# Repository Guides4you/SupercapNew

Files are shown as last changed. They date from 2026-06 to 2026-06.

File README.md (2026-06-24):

# Supercap New

A concise guide to the **Supercap New** project: repository layout, build requirements, programming instructions, hardware notes, and TAG configuration.

---

## Folder structure
- **Firmware** — firmware source code.  
- **Images** — binary firmware files.  
- **Hardware** — Altium project files and production outputs.

---

## Firmware
- **Required tools**: Visual Studio Code and **nRF Connect SDK v2.3.0**.  
- **Important**: builds will fail with other SDK versions; use exactly **v2.3.0** for reliable results.  
---

## Images and Programming
- **Target MCU**: **nRF52805**.  
- **Programmers supported**: Segger (J-Flash), Nordic programmer (`nrfjprog`), or other Segger tools.  
- **Common issue**: if the board’s **RESET** pin is not configured as a GPIO, the board may not boot after programming.  
- **Post-programming step (Windows)**: if needed, run the UICR erase command to restore RESET behavior:

`nrfjprog --eraseuicr -f NRF52`

---

## Hardware
- **Open with**: Altium Designer.  
- **Project outputs**: two production variants are included (with and without ePaper). Each variant contains production files and PDF schematics.  

---

## TAG configuration
- **Purpose**: TAGs are programmed with a **URI string** (web address) and an optional text configuration file.  
- **Configuration format**: `+pwr+adv+ep`  
- **pwr** — Bluetooth transmit power (integer).
  
| pwr value | nRF52 TX Power Setting |
|---|---|
| 0 | -40 dBm |
| 1 | -20 dBm |
| 2 | -16 dBm |
| 3 | -12 dBm |
| 4 | -8  dBm |
| 5 | -4  dBm |
| 6 | 0 dBm |
| 7 | +3  dBm |
| 8 | +4  dBm | 
- **adv** — advertising time in **seconds × 10** (integer).  
- **ep** — ePaper flag: `1` = enabled, `0` = disabled.  
- **Default configuration**:
> +6+10+1

- **Behavior**: after the first boot the configuration file is hidden; every time the TAG is written the device reboots.

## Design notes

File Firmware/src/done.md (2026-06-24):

# Modifiche eseguite

## Pinout e devicetree

1. `DISP_CS` spostato su `P0.21`
   - Label devicetree: `csgpios`
   - File: `../g4y_beacon_supercap.overlay`
   - Nota: `P0.21` nasce come reset, ma il progetto ha `CONFIG_GPIO_AS_PINRESET=n` in `prj.conf` e `prj_debug.conf`.

2. `GPO` della memoria NFC collegato a `P0.04`
   - Label devicetree: `nfcgpo`
   - File: `../g4y_beacon_supercap.overlay`
   - `VOUTNFC` non e' piu' usato come ingresso GPIO.

## Migrazione NFC a ST25DV04KC

3. Aggiornati indirizzi e registri base del driver NFC
   - User memory I2C: `0x53`
   - System memory I2C: `0x57`
   - Dynamic registers: `0x2000+`
   - File: `NfcTag.h`, `NfcTag.c`

4. Adattata la dimensione memoria per ST25DV04KC
   - `EEPROM_I2C_LENGTH` portato a `512` byte.

5. Disattivate le vecchie logiche M24LR non compatibili
   - Vecchie funzioni password/protection M24LR rese no-op dove non direttamente compatibili.
   - Mantenuta l'API esistente per non rompere il resto del firmware.

6. Aggiunta protezione base sul parsing NDEF URL
   - Il buffer URL viene terminato con `\0`.
   - Limitata la copia rispetto a `URL_BUFFER`.

## GPO e rilevamento scrittura NFC

7. Configurato `GPO` per segnalare scritture RF/NFC in EEPROM
   - `GPO1 = GPO_EN | RF_WRITE_EN`
   - La configurazione usa la password I2C factory-default a zero.
   - La password NFC/RF resta indipendente e puo' essere cambiata in produzione.

8. Gestione interrupt su GPO
   - `P0.04` configurato come input.
   - Interrupt su `GPIO_INT_EDGE_FALLING`, coerente con ST25DV04KC TSSOP open-drain e pull-up esterno.
   - Al trigger viene letto `IT_STS_Dyn` e si procede solo se il bit `RF_WRITE` e' attivo.

9. Logica post-scrittura NFC invariata lato comportamento applicativo
   - Dopo scrittura NFC, il firmware rileggge i dati.
   - Se URL/power/adv/epaper cambiano, esegue `sys_reboot(SYS_REBOOT_COLD)`.
   - L'aggiornamento BLE advertising avviene al boot successivo ricostruendo payload e parametri dai dati NFC.

## Energy harvesting / supercap

10. Configurata Energy Harvesting in modalita' on-demand
    - `EH_MODE = 1`
    - `EH_CTRL_Dyn.EH_EN` disabilitato durante init e prima della rilettura NFC.
    - `EH_CTRL_Dyn.EH_EN` abilitato dopo boot/lettura/display update e dopo gestione evento NFC.

11. Sequenza compatibile con AN4913
    - Energy harvesting disabilitato durante la fase critica di comunicazione NFC/RF.
    - Energy harvesting riabilitato solo dopo completamento lettura/scrittura, per ricaricare il supercap tramite `V_EH`.

## E-paper opzionale

12. Aggiunta define compile-time per presenza e-paper
    - File: `../inc/main.h`
    - Define: `DEVICE_HAS_EPAPER`

13. Disattivate le logiche display quando `DEVICE_HAS_EPAPER == 0`
    - Escluse chiamate a:
      - `Epaper_InitQR()`
      - `Epaper_Init()`
      - `Epaper_PrintQR()`
      - `Epaper_Gosleep()`
    - L'aggiornamento dei dati BLE da NFC resta attivo anche senza e-paper.

## Note di verifica

14. P0.21 come GPIO
    - Il firmware/devicetree lo configura come GPIO.
    - Su hardware gia' programmato va verificato `UICR.PSELRESET`: se contiene ancora `P0.21`, serve cancellazione UICR/recover.

15. Build non eseguita
    - `west`, `cmake` e `ninja` non risultano disponibili nel PATH della shell usata.

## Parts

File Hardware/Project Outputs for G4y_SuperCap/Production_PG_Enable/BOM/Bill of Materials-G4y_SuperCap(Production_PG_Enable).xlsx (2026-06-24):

Name | Description | Designator | Footprint | Quantity | Value | PartNumber | LCSC | LCSC_Alt_1 | LCSC_Alt_2
Cap_0402_100n/16V | 16V 100nF X7R ±10% 0402 Multilayer Ceramic Capacitors MLCC - SMD/SMT ROHS | C3, C17, C21, C24, C27 | C0402 | 5 | 100nF/16V | CL05B104KO5NNNC | C1525 | C22435936 | C576716
Cap_0402_10nF/50V | 10nF ±10% 50V Ceramic Capacitor X7R 0402 | C25 | C0402 | 1 | 10nF/50V | CL05B103KB5NNNC | C15195 | C6119808 | C5137480
Cap_0603_1uF/50V | 50V 1uF X5R ±10% 0603 Ceramic Capacitors ROHS | C16, C22 | C0603 | 2 | 1uF/50V | CL10A105KB8NNNC | C15849 | C6119852 | C380313
R_R0402_0R | 0Ω 62.5mW 50V Thick Film Resistor ±5% 0402 Chip Resistor - Surface Mount ROHS | R14, R33 | R0402 | 2 | 0r | 0402WGJ0000TCE | C21376 | C106231 | C2906877
R_R0402_1M5 | 1.5MΩ ±1% 62.5mW 0402 Thick Film Resistor | R11 | R0402 | 1 | 1M5 | 0402WGF1504TCE | C22276 | C49653927 | C2930014
R_R0402_22R | 22Ω ±1% 62.5mW 0402 Thick Film Resistor | R19, R20, R21, R22, R23, R24, R25, R27, R30 | R0402 | 9 | 22R | 0402WGF220JTCE | C25092 | C49654869 | C2929994
R_R0402_39r | 39Ω ±1% 62.5mW 0402 Thick Film Resistor | R32 | R0402 | 1 | 39r | 0402WGF390JTCE | C25110 | C2770700 | C2909354
R_R0402_1k | 0402, 1% ,63mW | R34 | R0402 | 1 | 1k | 0402WGJ0102TCE | C25543
R_R0402_100k | 0402, 1% ,63mW | R31 | R0402 | 1 | 100k | ERA-2VEB1003X | C25741
R_R0402_4k7 | 0402, 1% ,63mW | R28, R29 | R0402 | 2 | 4k7 | 0402WGF4701TCE | C25900
R_R0402_1M | 1MΩ ±1% 62.5mW 0402 Thick Film Resistor | R16, R18 | R0402 | 2 | 1M | 0402WGF1004TCE | C26083 | C2909328 | C2770623
R_R0402_221k | 221kΩ ±1% 62.5mW 0402 Thick Film Resistor | R3, R4, R9, R10 | R0402 | 4 | 221k | 0402WGF2213TCE | C26998 | C2998126 | C49653699
Cap_0402_1uF/25V | 1uF ±10% 25V Ceramic Capacitor X5R 0402 | C4, C5, C6, C7, C8, C9, C11, C14 | C0402 | 8 | 1uF/25V | CL05A105KA5NQNC | C52923 | C7393852 | C7472946
MBR0530T1G | Diode 30V 500mA Surface Mount SOD-123 | D1, D2, D3 | FP-SOD123-MFG | 3 |  | MBR0530T1G | C82046 | C5204746 | C236079
Diode_1N4148WT | Diode Independent 80V 125mA Surface Mount SOD-523 | D5 | SODFL160X65-2N | 1 |  | 1N4148WT-7 | C83482 | C727112 | C5381437
Cap_1206_47uF/10V | 47uF ±20% 10V Ceramic Capacitor X5R 1206 | C10 | C1206 | 1 | 47uF/10V | CL31A476MPHNNNE | C96123 | C7432787 | C6119971
Cap_0805_22uF/16V | 22uF ±20% 16V Ceramic Capacitor X5R 0805 | C1, C2, C12, C23 | C0805 | 4 | 22uF/16V | CL21A226MOQNNNE | C98190 | C33546008 | C6119898
BSS84AKBSS84AK,215 | P-Channel 50V 180mA 420mW Surface Mount SOT-23 | Q2 | SOT-23-3 | 1 |  | BSS84AK,215 | C127273 | C549760 | C7379993
TPS22860DBVR | Ultra-Low Leakage Current Single-Channel Load Switch | U2 | SOT-23-6 | 1 |  | TPS22860DBVR | C132005
PMV65UNER | N-Channel 20V 2.8A 940mW Surface Mount SOT-23 | Q1 | SOT-23-3 | 1 |  | PMV65UNER | C179446
10uH_1.44A_NRS4018T100MDGJ | 1.2A 10uH ±20% 1.3A 150mΩ SMD,4x4mm Fixed Inductors RoHS | L2 | FP-NRS4018-MFG | 1 | 10uH |  | C222882 | C2041931
R_R0402_2M7 | 2.7MΩ ±1% 62.5mW 0402 Thick Film Resistor | R13 | R0402 | 1 | 2M7 | 0402WGF2704TCE | C270621 | C3013160 | C49653355
Cap_0603_4u7F/35V | 4.7uF ±10% 35V Ceramic Capacitor X5R 0603 | C15 | C0603 | 1 | 4u7F/25V | CL10A475KL8NRNC | C307467 | C6119851 | C22367829
R_R0402_0r47 | 0402, 1% ,63mW | R17 | R0402 | 1 | 0r47 | RL0402JR-070R47L | C423162
R_R0402_2M55 | 2.55MΩ ±1% 62.5mW 0402 Thick Film Resistor | R15 | R0402 | 1 | 2M55 | 0402WGF2554TCE | C423206 | C477654 | 2612093
R_R0402_18M | 0402, 1% ,63mW | R2 | R0402 | 1 | 18M | 0402WGF1805TCE | C423222
R_R0402_4M7 | 4.7MΩ ±1% 62.5mW 0402 Thick Film Resistor | R1, R12 | R0402 | 2 | 4M7 | 0402WGF4704TCE | C474132 | C354978 | C49654986
ADP5091ACPZ-2-R7 | -40℃~+125℃ 100mV~3.3V 1A 2V 360nA Charging IC、Protection IC Not supported Supercapacitor、Lithium Battery LFCSP-24(4x4) Battery Management ROHS | U1 | FP-CP-24-14-IPC_B | 1 |  | ADP5091ACPZ-2-R7 | C579259
R_R0402_6M65 | 6.65MΩ ±1% 62.5mW 0402 Thick Film Resistor | R5, R6, R8 | R0402 | 3 | 6M65 | 0402WGF6654TCE | C620472 | C172116 | C477773
F3311A7H121024E200 | FFC/FPC Connector 24 Position 0.5mm Pitch Double-Sided Contacts, Top and Bottom Entry Surface Mount, Right Angle -55℃~+85℃ | CN1 | F3311A7H121024E200 | 1 |  | F3311A7H121024E200 | C3168055 | C52722656 | C48678015
Inductor_22uH_550mA | 550mA 22uH ±20% 685mΩ 650mA 1210 Fixed Inductors RoHS | L1 | FP-LQH32PB_NC-MFG | 1 | 22uH |  | C4153652 | C53224120 | C22463994
ST25DV04KC-IE6T3 | 53Kbit/s ISO 15693,NFC I2C TSSOP-8 RFID, RF Access, Monitoring ICs RoHS | U4 | TSOP65P640X120-8N | 1 |  | ST25DV04KC-IE6T3 | C5221719 | C5267455
BLE Module | Bluetooth Modules - 802.15.1 Bluetooth Low Energy, BLE 5.2 Module using Nordic nRF52805 SoC with integrated antenna | U3 | BC805M | 1 |  | BC805M | C6751361
Cap_0805_4u7F/50V | 4.7uF ±10% 50V Ceramic Capacitor X5R 0805 | C13 | C0805 | 1 | 4u7F/50V | HGC0805R5475K500NSLJ | C7472969 | C513770 | C2903668

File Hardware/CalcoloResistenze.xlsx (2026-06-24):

 | Vref | 1.011
 |  |  |  |  |  |  |  |  | r avab
R7 | RBK1 | 0 |  | VSETBK |  |  |  |  | 0.15 | VSETPG_RISING | 3.80
R14 | RBK2 | 0 |  |  | VSETBK | #DIV/0! | Passaggio dalla batteria di backup |  | 0.221 | VSETPG_FALLING | 2.50
 |  |  |  |  |  |  |  |  | 2.32
R8 | RTERM1 | 6.65 |  | VBAT_TERM | VBAT_TERM | 5.47 | Termine carica |  | 2.55 | RPG1 | 6.7
R15 | RTERM2 | 2.55 |  |  | VBAT_TERM_HYS | 5.31 |  |  | 2.7 | RPG_HYST | 1.5
 |  |  |  |  |  |  |  |  | 3.32 | RPG2 | 2.9
R6 | RPG1 | 6.65 |  | VSETPG_RISING VSETPG_FALLING |  |  |  |  | 3.48
R11 | RPG_HYST | 1.5 |  |  | VSETPG_RISING | 3.76 | PG alzato | 1.25 | 3.74
R13 | RPG2 | 3 |  |  | VSETPG_FALLING | 2.51 | PG abbassato |  | 4.7
 |  |  |  |  |  |  |  |  | 9.1
R5 | Rsd1 | 6.65 |  | VSETSD | VSETSD_HYS |  |  |  | 10
R12 | Rsd2 | 4.7 |  |  | VSETSD | 2.44 | Protezione csarica batteria |  | 18
 |  |  |  |  | VSYS_CHG | 2,19 | Start Charging BAT Threshold on SYS
 |  |  |  |  | VSYS_CHG_HYS | 2.04
 |  |  |  |  | VSYS_TH | 1,87 | V cold start
 |  |  |  |  | 0V
Demoboard value
 | Vref | 1.011 |  |  | VSETBK | 2.53 | Passaggio dalla batteria di backup
R5 | Rsd1 | 5.9 | 6.65
RR12 | Rsd2 | 4.12 | 3.48
R6 | RPG1 | 6.19 | 6.65 |  | VBAT_TERM | 3.69 | Termine carica
R11 | RPG_HYST | 0.1 | 1 |  | VBAT_TERM_HYS | 3.58
R13 | RPG2 | 3.83 | 2.32
 |  |  |  |  | VSETPG_RISING | 2.67 | PG alzato
R7 | RBK1 | 6.04 | 6.65 |  | VSETPG_FALLING | 2.60 | PG abbassato
R14 | RBK2 | 4.02 | 3.32
 |  |  |  |  | VSETSD_HYS
R8 | RTERM1 | 5.9 | 6.65 |  | VSETSD | 2.46 | Protezione csarica batteria
R15 | RTERM2 | 4.12 | 3.74
 |  |  |  |  | VSYS_CHG | 2,19 | Start Charging BAT Threshold on SYS
 |  |  |  |  | VSYS_CHG_HYS | 2.04
 |  |  |  |  | VSYS_TH | 1,87 | V cold start
 |  |  |  |  | 0V

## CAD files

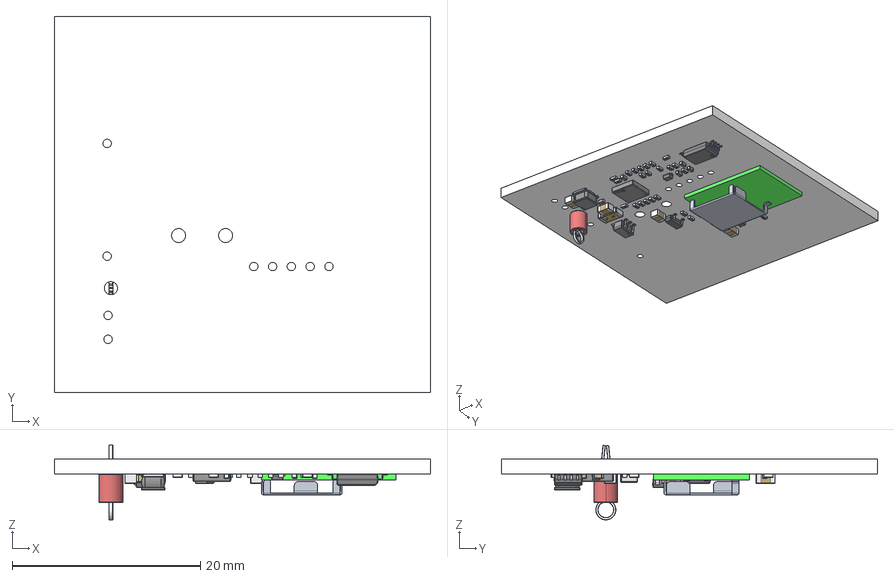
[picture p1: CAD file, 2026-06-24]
Hardware/Project Outputs for G4y_SuperCap/Production_PG_Enable_noDisplay/ExportSTEP/G4y_SuperCap(Production_PG_Enable_noDisplay).step
40.0 x 40.0 x 7.96 mm
LEAD x 6
Texas Logo Yury - Copy
Texas Logo Yury
User Library-R_0402 x 23
lead x 2
User Library-Capacitor 0402 x 6
TEST POINT RED D1mm
User Library-CAPC2013X10 x 4
pads
Analog Devices Logo
Murata
BC805
BC805M
Leader x 8
SOT23

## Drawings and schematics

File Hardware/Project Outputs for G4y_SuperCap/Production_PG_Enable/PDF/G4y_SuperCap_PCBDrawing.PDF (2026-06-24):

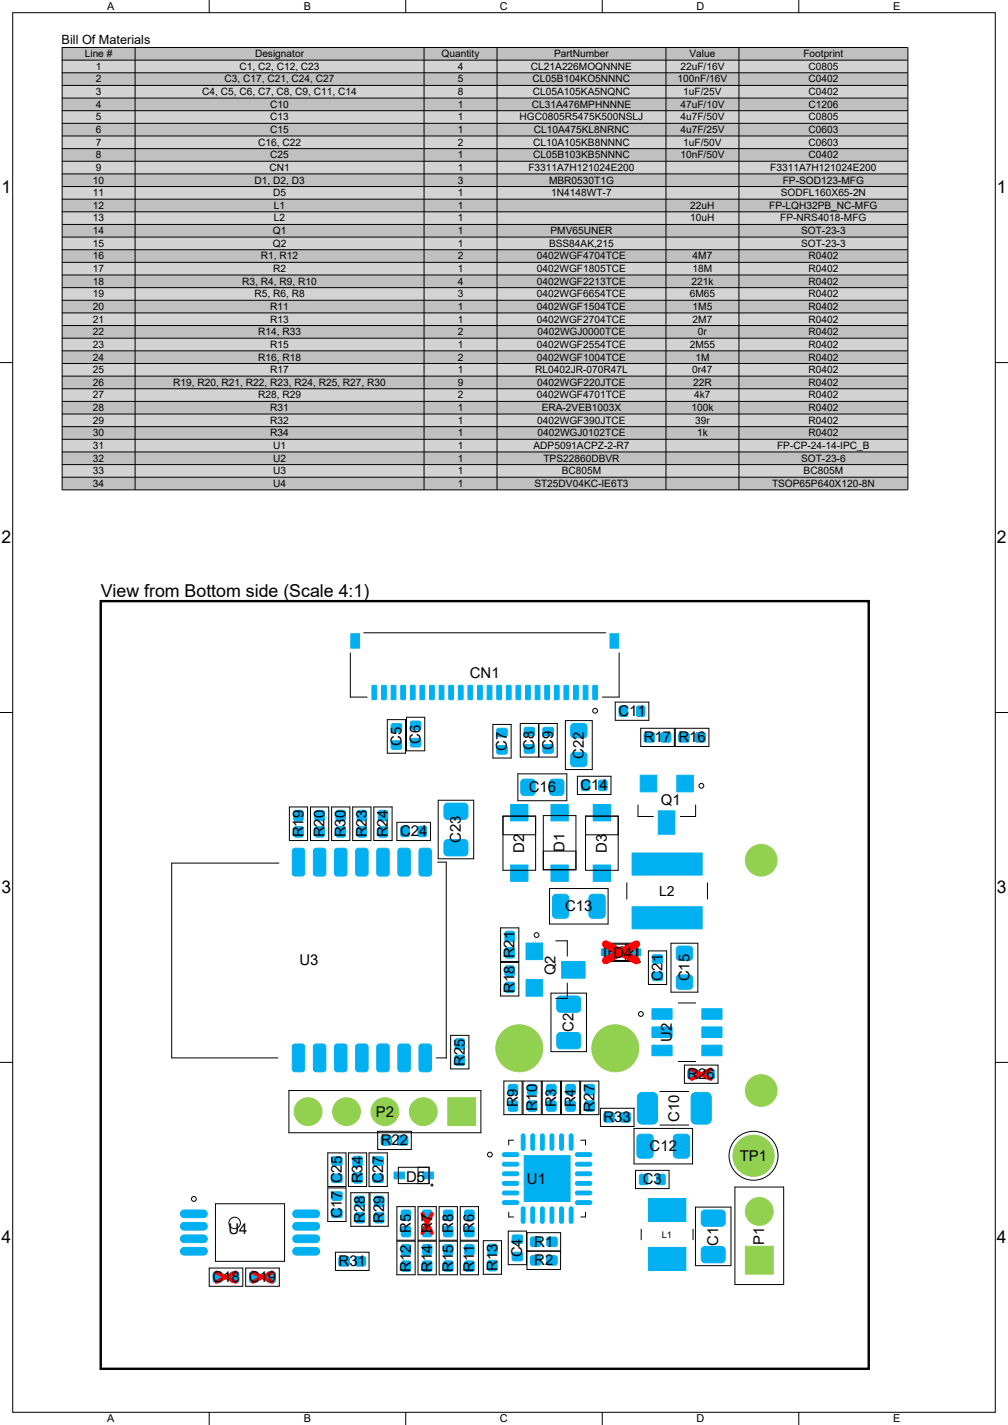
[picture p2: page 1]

Line # | Designator | Quantity | PartNumber | Value | Footprint
1 | C1, C2, C12, C23 | 4 | CL21A226MOQNNNE | 22uF/16V | C0805
2 | C3, C17, C21, C24, C27 | 5 | CL05B104KO5NNNC | 100nF/16V | C0402
3 | C4, C5, C6, C7, C8, C9, C11, C14 | 8 | CL05A105KA5NQNC | 1uF/25V | C0402
4 | C10 | 1 | CL31A476MPHNNNE | 47uF/10V | C1206
5 | C13 | 1 | HGC0805R5475K500NSLJ | 4u7F/50V | C0805
6 | C15 | 1 | CL10A475KL8NRNC | 4u7F/25V | C0603
7 | C16, C22 | 2 | CL10A105KB8NNNC | 1uF/50V | C0603
8 | C25 | 1 | CL05B103KB5NNNC | 10nF/50V | C0402
9 | CN1 | 1 | F3311A7H121024E200 | | F3311A7H121024E200
10 | D1, D2, D3 | 3 | MBR0530T1G | | FP-SOD123-MFG
11 | D5 | 1 | 1N4148WT-7 | | SODFL160X65-2N
12 | L1 | 1 | | 22uH | FP-LQH32PB_NC-MFG
13 | L2 | 1 | | 10uH | FP-NRS4018-MFG
14 | Q1 | 1 | PMV65UNER | | SOT-23-3
15 | Q2 | 1 | BSS84AK,215 | | SOT-23-3
16 | R1, R12 | 2 | 0402WGF4704TCE | 4M7 | R0402
17 | R2 | 1 | 0402WGF1805TCE | 18M | R0402
18 | R3, R4, R9, R10 | 4 | 0402WGF2213TCE | 221k | R0402
19 | R5, R6, R8 | 3 | 0402WGF6654TCE | 6M65 | R0402
20 | R11 | 1 | 0402WGF1504TCE | 1M5 | R0402
21 | R13 | 1 | 0402WGF2704TCE | 2M7 | R0402
22 | R14, R33 | 2 | 0402WGJ0000TCE | 0r | R0402
23 | R15 | 1 | 0402WGF2554TCE | 2M55 | R0402
24 | R16, R18 | 2 | 0402WGF1004TCE | 1M | R0402
25 | R17 | 1 | RL0402JR-070R47L | 0r47 | R0402
26 | R19, R20, R21, R22, R23, R24, R25, R27, R30 | 9 | 0402WGF220JTCE | 22R | R0402
27 | R28, R29 | 2 | 0402WGF4701TCE | 4k7 | R0402
28 | R31 | 1 | ERA-2VEB1003X | 100k | R0402
29 | R32 | 1 | 0402WGF390JTCE | 39r | R0402
30 | R34 | 1 | 0402WGJ0102TCE | 1k | R0402
31 | U1 | 1 | ADP5091ACPZ-2-R7 | | FP-CP-24-14-IPC_B
32 | U2 | 1 | TPS22860DBVR | | SOT-23-6
33 | U3 | 1 | BC805M | | BC805M
34 | U4 | 1 | ST25DV04KC-IE6T3 | | TSOP65P640X120-8N

View from Bottom side (Scale 4:1)

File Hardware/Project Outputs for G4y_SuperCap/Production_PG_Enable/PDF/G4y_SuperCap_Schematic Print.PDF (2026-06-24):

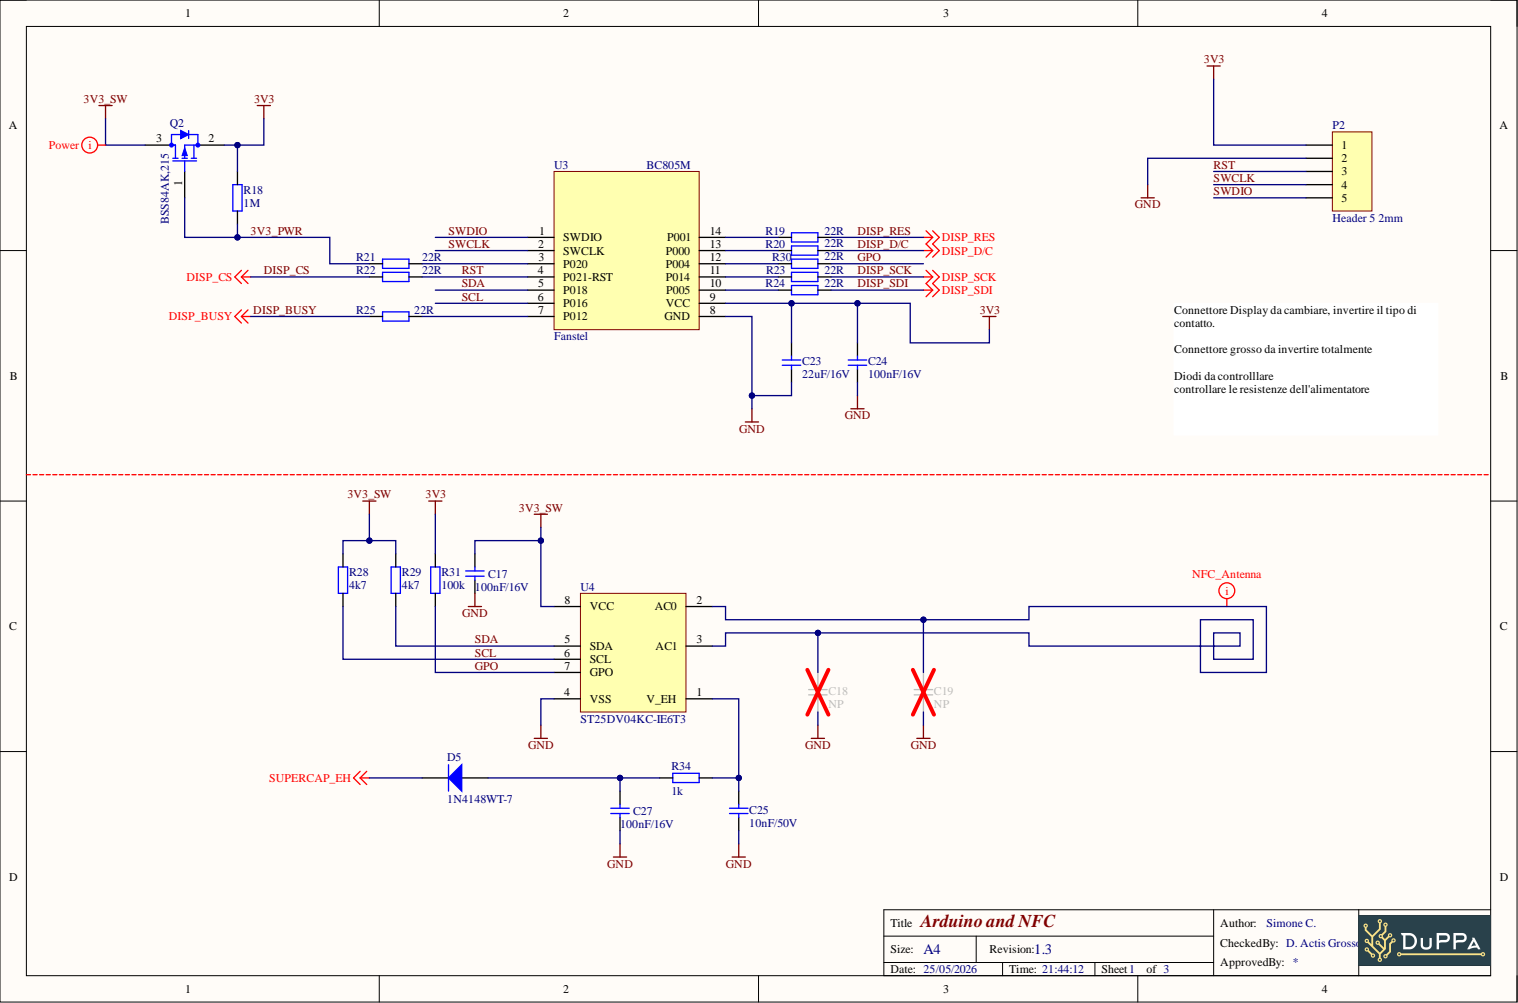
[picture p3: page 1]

Connettore Display da cambiare, invertire il tipo di
contatto.

Connettore grosso da invertire totalmente

Diodi da controlllare
controllare le resistenze dell'alimentatore

GND SDA | SDA 5

SCL | SCL 6
GPO | GPO 7

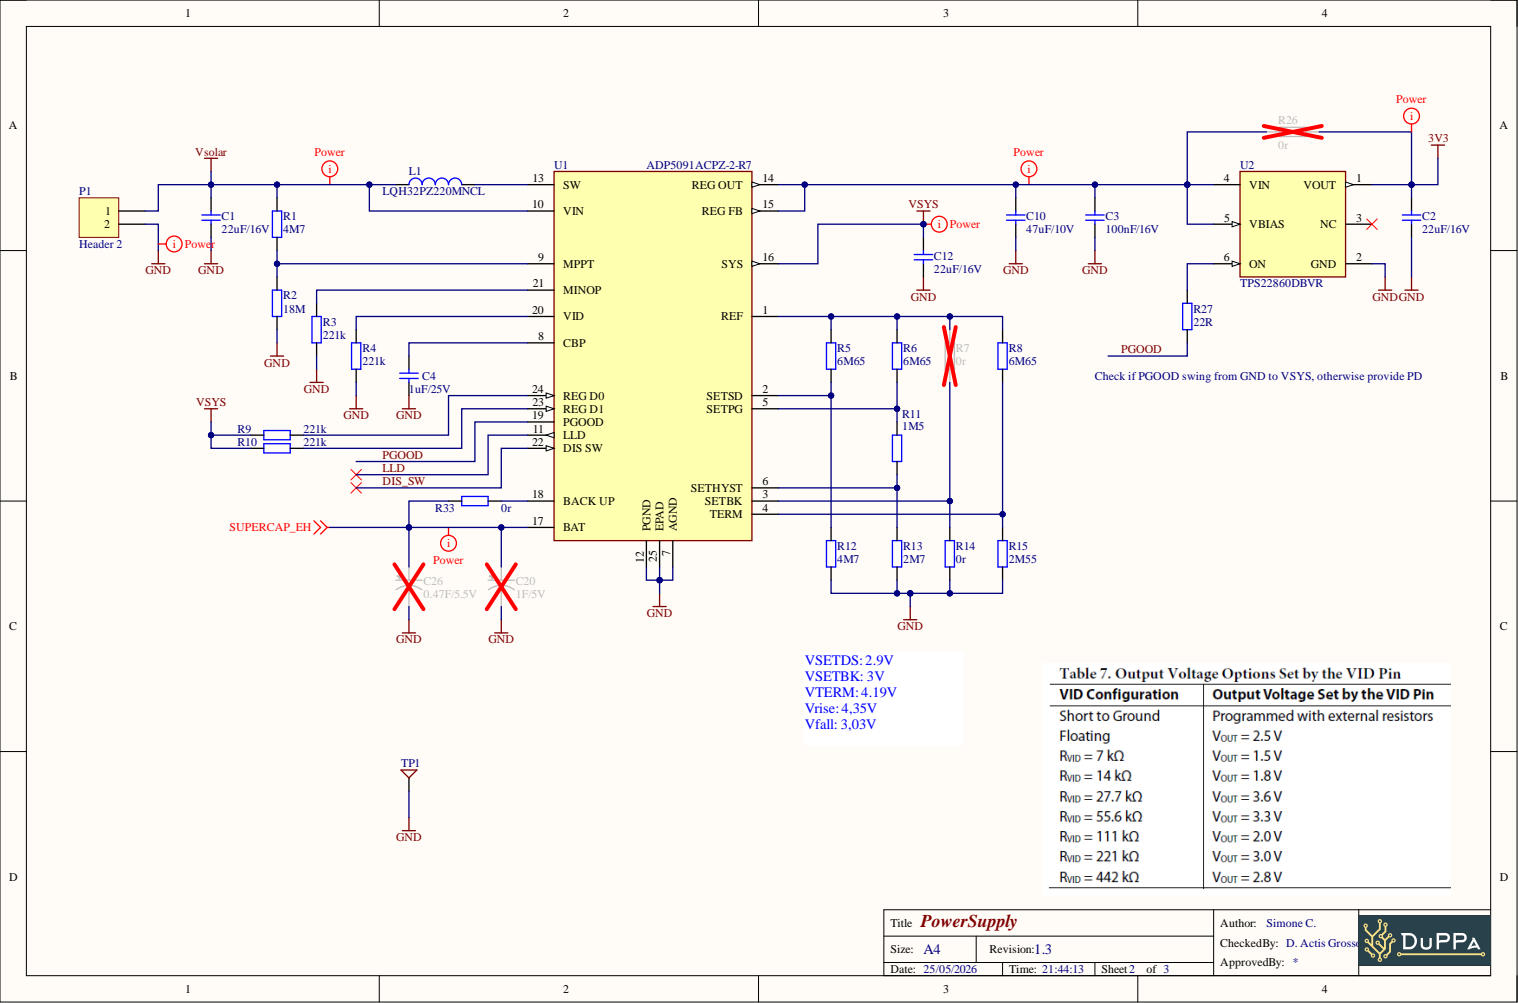
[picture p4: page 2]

G N D | 1 9 | 3 SETHYST 6

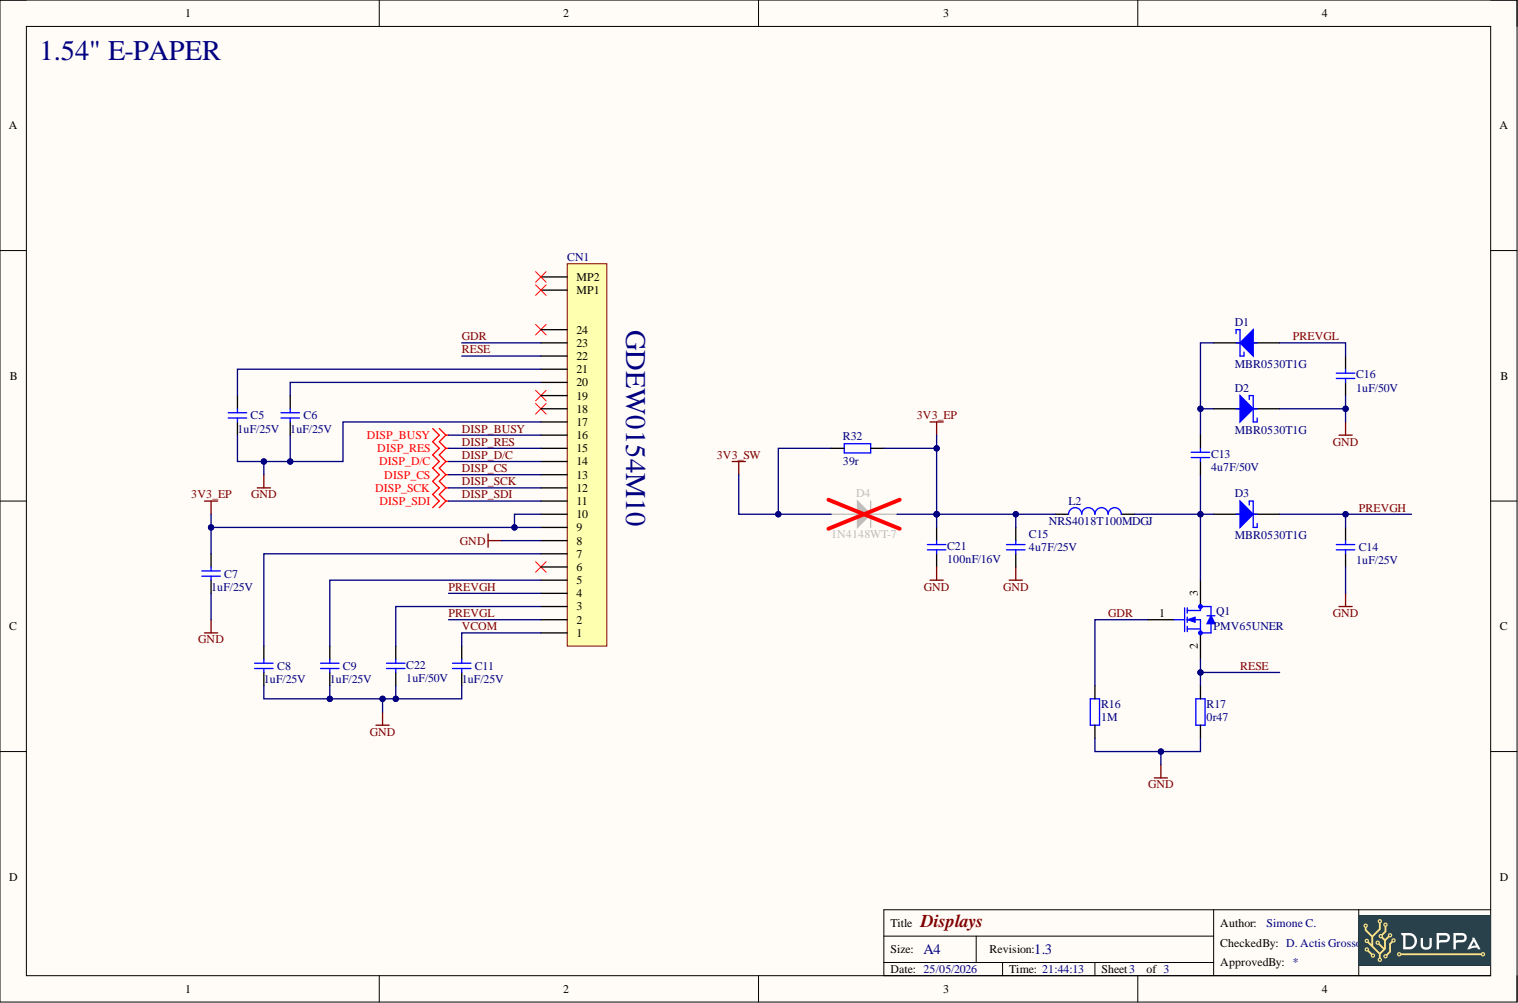
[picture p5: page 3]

PRE V GH

PRE V G L VCO M

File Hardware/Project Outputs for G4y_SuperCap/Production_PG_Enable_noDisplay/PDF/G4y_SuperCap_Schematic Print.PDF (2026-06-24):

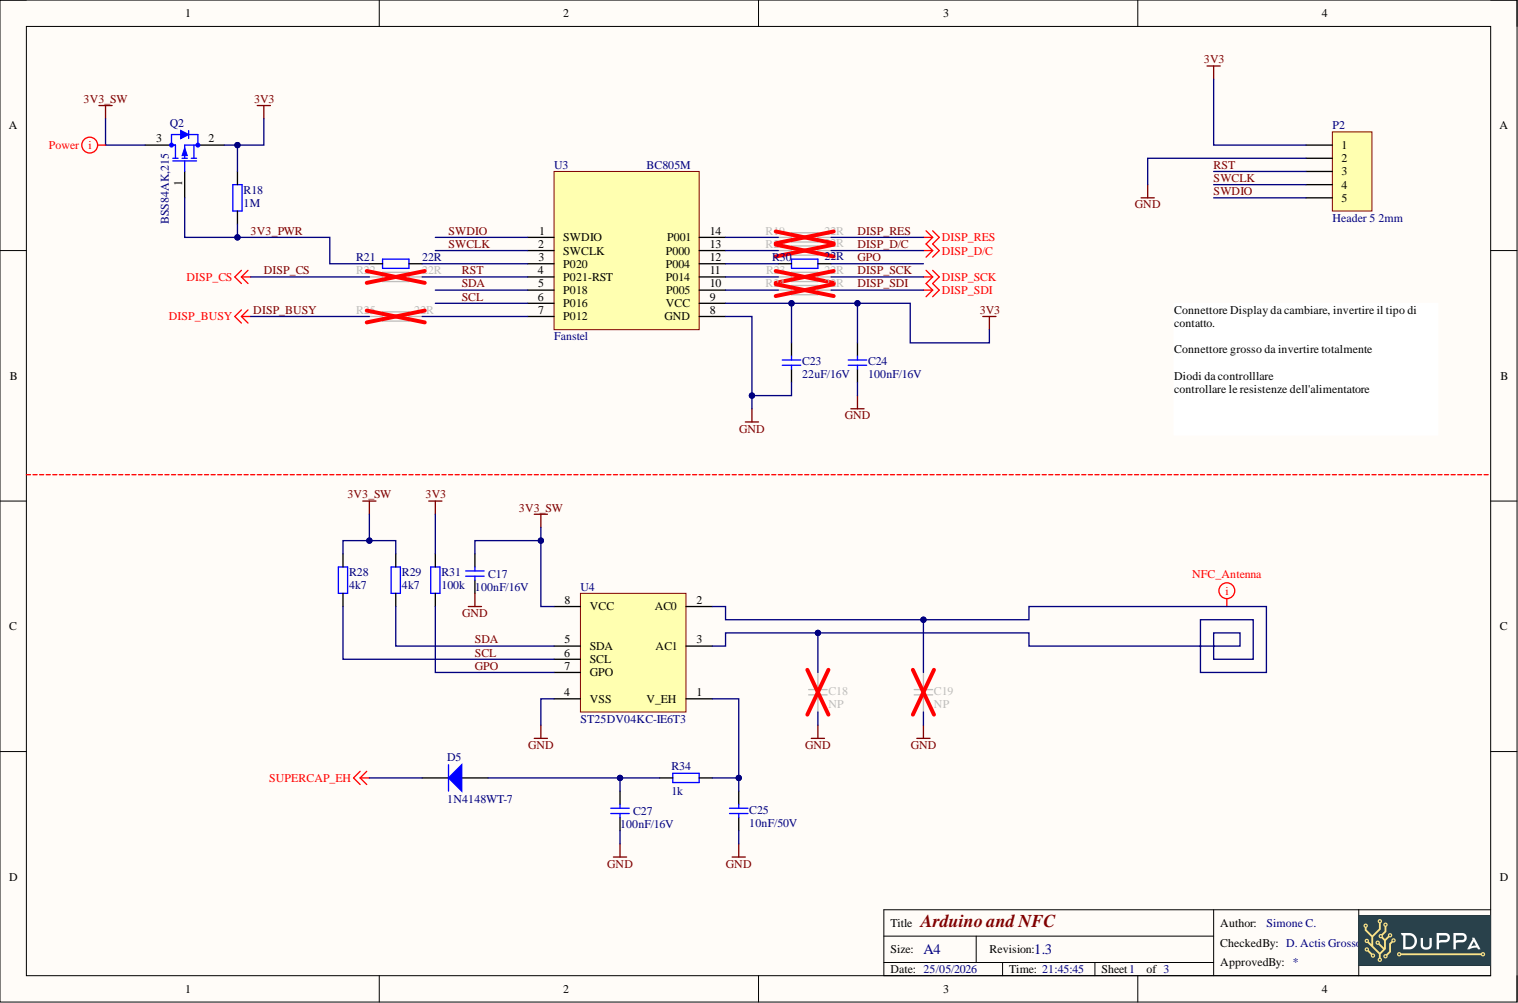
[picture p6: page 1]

Connettore Display da cambiare, invertire il tipo di
contatto.

Connettore grosso da invertire totalmente

Diodi da controlllare
controllare le resistenze dell'alimentatore

GND SDA | SDA 5

SCL | SCL 6
GPO | GPO 7

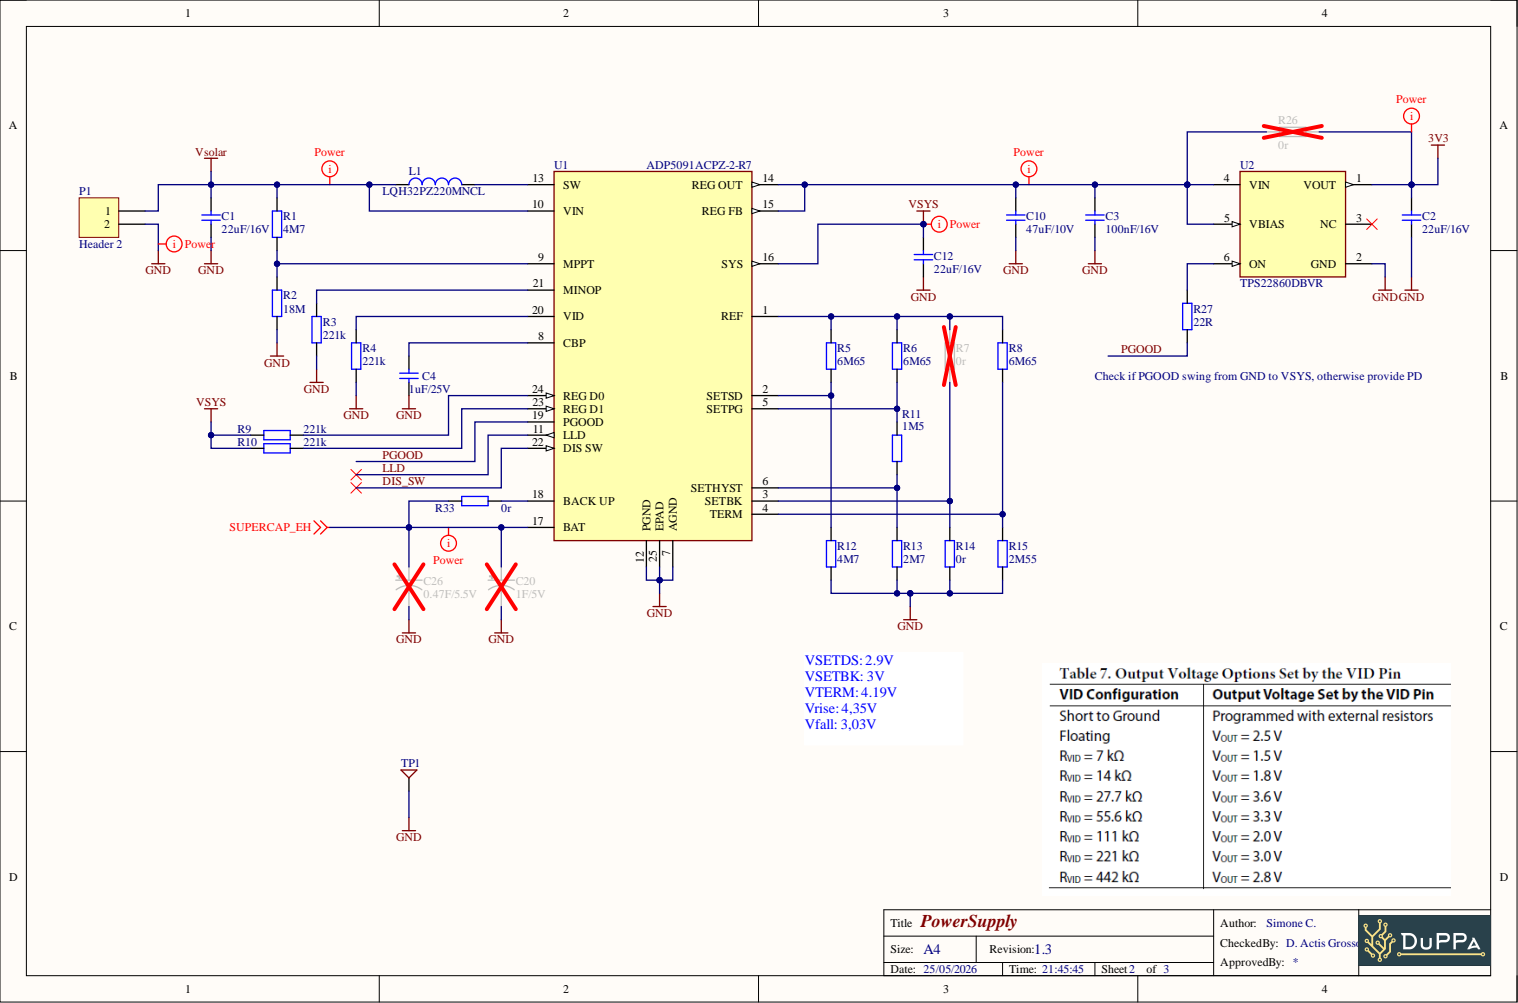
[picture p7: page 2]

G N D | 1 9 | 3 SETHYST 6

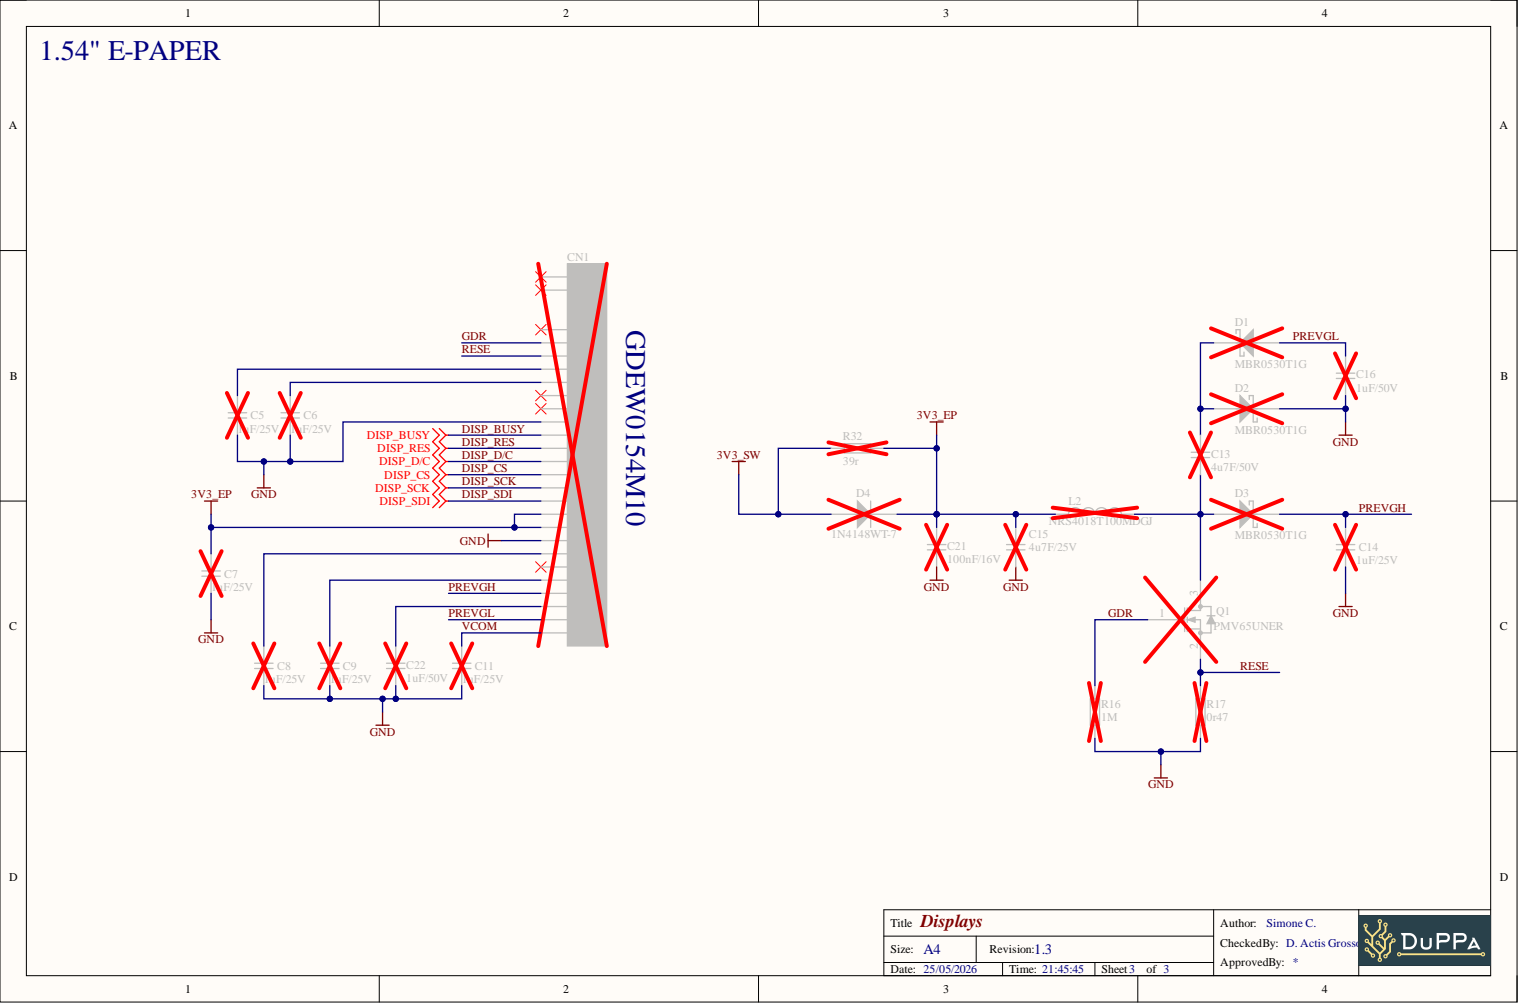
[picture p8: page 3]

PRE V GH

PRE V G L VCO M

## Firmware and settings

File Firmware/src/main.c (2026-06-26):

/* main.c - Application main entry point */

/*
 * Copyright (c) 2015-2016 Intel Corporation
 *
 * SPDX-License-Identifier: Apache-2.0
 */

#include <zephyr/types.h>
#include <stddef.h>
#include <zephyr/sys/util.h>
#include <zephyr/sys/byteorder.h>
#include <zephyr/drivers/gpio.h>
#include <zephyr/bluetooth/bluetooth.h>
#include <zephyr/bluetooth/hci.h>
#include <zephyr/bluetooth/hci_vs.h>
#include <zephyr/sys/reboot.h>
#include <zephyr/toolchain.h>
#include <zephyr/pm/pm.h>
#include <zephyr/pm/policy.h>
#include <zephyr/pm/device.h>
#include "../../zephyr/subsys/bluetooth/controller/include/ll.h"
#include <zephyr/drivers/i2c.h>
#include <errno.h>
#include <zephyr/kernel.h>
#include <zephyr/device.h>

#include "NfcTag.h"
#include "GDEW0154M10.h"
#include "epaper.h"
#include "main.h"

//*** After writing send the command nrfjprog --reset

#define DEVICE_NAME CONFIG_BT_DEVICE_NAME
#define DEVICE_NAME_LEN (sizeof(DEVICE_NAME) - 1)

#define NFC_GPO_WAIT_TIME 10000

struct bt_le_adv_param ble_par;

uint8_t buffer_URL[URL_BUFFER] = {0};
uint8_t buffer_check_URL[URL_BUFFER] = {0};
uint8_t adv, epaper;
uint8_t check_adv, check_epaper, power, check_power;

int8_t bt_power;

/*
 * Set Advertisement data. Based on the Eddystone specification:
 * https://github.com/google/eddystone/blob/master/protocol-specification.md
 * https://github.com/google/eddystone/tree/master/eddystone-url
 */

struct gpio_dt_spec pwr_pin = GPIO_DT_SPEC_GET(DT_NODELABEL(pwrgpios), gpios);
struct gpio_dt_spec nfc_gpo_pin = GPIO_DT_SPEC_GET(DT_NODELABEL(nfcgpo), gpios);

void set_tx_power(uint8_t handle_type, uint16_t handle, int8_t tx_pwr_lvl);

static struct gpio_callback nfc_gpo_cb;
K_SEM_DEFINE(nfc_gpo_sem, 0, 1);

#define Power_EN()                                \
	gpio_pin_configure_dt(&pwr_pin, GPIO_OUTPUT); \
	gpio_pin_set_dt(&pwr_pin, 0);                 \
	k_msleep(100);
// #define Power_DI() gpio_pin_set_dt(&pwr_pin, 1)

#define Power_DI() \
	k_msleep(20);  \
	gpio_pin_set_dt(&pwr_pin, 1)

uint8_t beacon_data[URL_BUFFER + 6] = {0};

static struct bt_data ad[3] = {
	BT_DATA_BYTES(BT_DATA_FLAGS, BT_LE_AD_NO_BREDR),
	BT_DATA_BYTES(BT_DATA_UUID16_ALL, 0xaa, 0xfe),
	{0}};

/* Set Scan Response data */
static struct bt_data sd[] = {
	BT_DATA(BT_DATA_NAME_COMPLETE, DEVICE_NAME, DEVICE_NAME_LEN),
};

/* Configure GPIO pads as pPin Reset pin if Pin Reset capabilities desired. If CONFIG_GPIO_AS_PINRESET is not
	defined, pin reset will not be available. One GPIO (see Product Specification to see which one) will then be
	reserved for PinReset and not available as normal GPIO. */

static void bt_ready(int err)
{
	char addr_s[BT_ADDR_LE_STR_LEN];
	bt_addr_le_t addr = {0};
	size_t count = 1;
	if (err)
	{
		return;
	}

	/* Start advertising */
	err = bt_le_adv_start(&ble_par, ad, ARRAY_SIZE(ad), sd, ARRAY_SIZE(sd));
	if (err)
	{
		return;
	}

	/* For connectable advertising you would use
	 * bt_le_oob_get_local().  For non-connectable non-identity
	 * advertising an non-resolvable private address is used;
	 * there is no API to retrieve that.
	 */

	bt_id_get(&addr, &count);
	bt_addr_le_to_str(&addr, addr_s, sizeof(addr_s));
	set_tx_power(BT_HCI_VS_LL_HANDLE_TYPE_ADV, 0, bt_power);
}

void set_tx_power(uint8_t handle_type, uint16_t handle, int8_t tx_pwr_lvl)
{
	struct bt_hci_cp_vs_write_tx_power_level *cp;
	struct bt_hci_rp_vs_write_tx_power_level *rp;
	struct net_buf *buf, *rsp = NULL;
	int err;

	buf = bt_hci_cmd_create(BT_HCI_OP_VS_WRITE_TX_POWER_LEVEL,
							sizeof(*cp));
	if (!buf)
	{
		return;
	}

	cp = net_buf_add(buf, sizeof(*cp));
	cp->handle = sys_cpu_to_le16(handle);
	cp->handle_type = handle_type;
	cp->tx_power_level = tx_pwr_lvl;

	err = bt_hci_cmd_send_sync(BT_HCI_OP_VS_WRITE_TX_POWER_LEVEL, buf, &rsp);
	if (err)
	{
		return;
	}

	rp = (void *)rsp->data;
	net_buf_unref(rsp);
}

void nfc_gpo_event(const struct device *dev, struct gpio_callback *cb, uint32_t pins)
{
	ARG_UNUSED(dev);
	ARG_UNUSED(cb);
	ARG_UNUSED(pins);

	k_sem_give(&nfc_gpo_sem);
}

int main(void)
{

	uint16_t adv_temp;
	k_msleep(5000);
	Power_EN();
	k_msleep(1000);
	NfcTag_init();

	//	uint8_t pwd[4]={0};
	// NfcTag_submitPassWd(pwd);

	//	NfcTag_clearSectorProtect();

	if (NFCGetData(&buffer_URL[0], &power, &adv, &epaper) == NFC_ERROR_READ)
	{
		strcpy(&buffer_URL[0], "URL_ERROR.com");
	}
	else
	{
		NfcTag_HideConfig(strlen(buffer_URL));
	}

	if (epaper == 1)
	{
		Epaper_InitQR(buffer_URL);
		Epaper_Init();
		Epaper_PrintQR();
	}

	switch (power)
	{
	case 0:
		bt_power = RADIO_TXPOWER_TXPOWER_Neg40dBm;
		break;

	case 1:
		bt_power = RADIO_TXPOWER_TXPOWER_Neg20dBm;
		break;

	case 2:
		bt_power = RADIO_TXPOWER_TXPOWER_Neg16dBm;
		break;

	case 3:
		bt_power = RADIO_TXPOWER_TXPOWER_Neg12dBm;
		break;

	case 4:
		bt_power = RADIO_TXPOWER_TXPOWER_Neg8dBm;
		break;

	case 5:
		bt_power = RADIO_TXPOWER_TXPOWER_Neg4dBm;
		break;

	case 6:
		bt_power = RADIO_TXPOWER_TXPOWER_0dBm;
		break;

	case 7:
		bt_power = RADIO_TXPOWER_TXPOWER_Pos3dBm;
		break;

	case 8:
		bt_power = RADIO_TXPOWER_TXPOWER_Pos4dBm;
		break;

	default:
		bt_power = RADIO_TXPOWER_TXPOWER_0dBm;
		break;
	}

	beacon_data[0] = 0xaa;	   /* Eddystone UUID MSB*/
	beacon_data[1] = 0xfe;	   /* Eddystone UUID LSB*/
	beacon_data[2] = 0x10;	   /* Eddystone-URL frame type */
	beacon_data[3] = bt_power; /* Calibrated Tx power in db */
	beacon_data[4] = 0x00;	   /* URL Scheme Prefix http://www. */
	strcpy(&beacon_data[5], buffer_URL);

	ad[2].data = (const uint8_t *)&beacon_data[0];
	ad[2].type = BT_DATA_SVC_DATA16;
	ad[2].data_len = strlen(buffer_URL) + 5;

	/* Initialize the Bluetooth Subsystem */

	ble_par.id = BT_ID_DEFAULT;
	ble_par.sid = 0;
	ble_par.secondary_max_skip = 0;
	ble_par.options = BT_LE_ADV_OPT_USE_IDENTITY;
	ble_par.peer = NULL;

	adv_temp = adv * 160;
	if (adv_temp < 0x0020)
	{
		adv_temp = 0x0020;
	}
	if (adv_temp > 0x4000)
	{
		adv_temp = 0x4000;
	}

	ble_par.interval_max = adv_temp;
	adv_temp = adv_temp - 10;
	if (adv_temp < 0x0020)
	{
		adv_temp = 0x0020;
	}
	ble_par.interval_min = adv_temp;

	bt_enable(bt_ready);

	set_tx_power(BT_HCI_VS_LL_HANDLE_TYPE_ADV, 0, bt_power);

	NfcTag_setEnergyHarvesting(false);
	NfcTag_GoSleep();
	if (epaper == 1)
	{
		Epaper_Gosleep();
	}
	Power_DI();

	gpio_pin_configure_dt(&nfc_gpo_pin, GPIO_INPUT);
	gpio_init_callback(&nfc_gpo_cb, nfc_gpo_event, BIT(nfc_gpo_pin.pin));
	gpio_add_callback(nfc_gpo_pin.port, &nfc_gpo_cb);
	gpio_pin_interrupt_configure_dt(&nfc_gpo_pin, GPIO_INT_EDGE_FALLING);

	while (1)
	{
		if (k_sem_take(&nfc_gpo_sem, K_MSEC(NFC_GPO_WAIT_TIME)) == 0)
		{
			Power_EN();
			NfcTag_Resume();
			//NfcTag_setEnergyHarvesting(false);
			if (NfcTag_wasRfWriteEvent() &&
				(NFCGetData(&buffer_check_URL[0], &check_power, &check_adv, &check_epaper) != NFC_ERROR_READ))
			{
				if ((strcmp(buffer_check_URL, buffer_URL) != 0) || (check_power != power) || (check_adv != adv) || (check_epaper != epaper))
				{
					//NfcTag_setEnergyHarvesting(true);
					sys_reboot(SYS_REBOOT_COLD);
				}
				else
				{
					buffer_check_URL[0] = 0;
					check_power = 0xFF;
					check_adv = 0xFF;
					check_epaper = 0xFF;
				}
			}
			//NfcTag_setEnergyHarvesting(true);
			NfcTag_GoSleep();
			Power_DI();
		}
	}
}

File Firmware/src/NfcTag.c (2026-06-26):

#include "NfcTag.h"
#include "main.h"
#include <stdio.h>
#include <errno.h>
#include <zephyr/kernel.h>
#include <zephyr/device.h>
#include <zephyr/drivers/gpio.h>
#include <zephyr/drivers/i2c.h>
#include <zephyr/sys/util.h>

/* I2C pins (TWIM SCL = P0.16) */
#define I2C_GPIO_DEV    DEVICE_DT_GET(DT_NODELABEL(gpio0))
#define I2C_SCL_PIN     16
#include <zephyr/pm/pm.h>
#include <zephyr/pm/policy.h>
#include <zephyr/pm/device.h>


#define NFC_BASE_ADDRESS ST25DV_I2C_USER_ADDR
#define NFC_SYSTEM_ADDRESS ST25DV_I2C_SYSTEM_ADDR
#define ST25DV_GPO_ENABLE 0x01
#define ST25DV_GPO_RF_WRITE_ENABLE 0x80
#define ST25DV_IT_STS_RF_WRITE 0x80
#define ST25DV_I2C_PRESENT_PASSWORD 0x09
#define ST25DV_EH_ON_DEMAND 0x01
#define ST25DV_EH_ENABLE 0x01
#define ST25DV_EH_DISABLE 0x00
#define ST25DV_MAX_I2C_WRITE 256
#define ST25DV_I2C_RETRY_COUNT 2
#define ST25DV_EEPROM_WRITE_MS 10

uint8_t NFC_I2C_ADDRESS;
const struct device *const i2c_nfc = DEVICE_DT_GET(DT_NODELABEL(i2c0));

/* RF/NFC passwords are independent; production changes only those. */
static const uint8_t st25dv_default_i2c_password[PASSWORD_LENGTH] = {0};
static bool st25dv_present_i2c_password(const uint8_t *passWd);
static uint8_t st25dv_read_byte_at(uint8_t i2c_address, unsigned int address, uint8_t *data);
static uint8_t st25dv_write_byte_at(uint8_t i2c_address, unsigned int address, uint8_t data);
static uint8_t st25dv_write_eeprom_byte_checked(uint8_t i2c_address, unsigned int address, uint8_t data);

void NfcTag_init(void)
{
    if (!device_is_ready(i2c_nfc))
    {
        return;
    }

    NFC_I2C_ADDRESS = NFC_BASE_ADDRESS;
    NfcTag_setEnergyHarvesting(false);
    (void)st25dv_write_byte_at(NFC_BASE_ADDRESS, ST25DV_GPO_CTRL_DYN_ADDR, ST25DV_GPO_ENABLE);
    if (st25dv_present_i2c_password(st25dv_default_i2c_password))
    {
        (void)st25dv_write_eeprom_byte_checked(NFC_SYSTEM_ADDRESS, ST25DV_GPO1_ADDR,
                                               ST25DV_GPO_ENABLE | ST25DV_GPO_RF_WRITE_ENABLE);
        (void)st25dv_write_eeprom_byte_checked(NFC_SYSTEM_ADDRESS, ST25DV_EH_MODE_ADDR,
                                               ST25DV_EH_ON_DEMAND);
    }
    NFC_I2C_ADDRESS = NFC_BASE_ADDRESS;
    (void)NfcTag_wasRfWriteEvent();
    k_msleep(10);
}

void NfcTag_GoSleep(void)
{
    /* Fissa SCL a LOW, poi sospende il periferico I2C. */
    pm_device_action_run(i2c_nfc, PM_DEVICE_ACTION_SUSPEND);
    gpio_pin_configure(I2C_GPIO_DEV, I2C_SCL_PIN, GPIO_OUTPUT);
    gpio_pin_set(I2C_GPIO_DEV, I2C_SCL_PIN, 0);
}

void NfcTag_Resume(void)
{

    pm_device_action_run(i2c_nfc, PM_DEVICE_ACTION_RESUME);
}

bool NfcTag_wasRfWriteEvent(void)
{
    uint8_t it_status;

    NFC_I2C_ADDRESS = NFC_BASE_ADDRESS;
    if (st25dv_read_byte_at(NFC_BASE_ADDRESS, ST25DV_IT_STS_DYN_ADDR, &it_status) != 0)
    {
        return false;
    }

    return (it_status & ST25DV_IT_STS_RF_WRITE) != 0;
}

void NfcTag_setEnergyHarvesting(bool enable)
{
    NFC_I2C_ADDRESS = NFC_BASE_ADDRESS;
    (void)st25dv_write_byte_at(NFC_BASE_ADDRESS, ST25DV_EH_CTRL_DYN_ADDR,
                               enable ? ST25DV_EH_ENABLE : ST25DV_EH_DISABLE);
}

static bool st25dv_present_i2c_password(const uint8_t *passWd)
{
    uint8_t sso;

    for (int attempt = 0; attempt < ST25DV_I2C_RETRY_COUNT; attempt++)
    {
        NfcTag_submitPassWd((uint8_t *)passWd);
        k_msleep(ST25DV_EEPROM_WRITE_MS);

        if ((st25dv_read_byte_at(NFC_BASE_ADDRESS, ST25DV_I2C_SSO_DYN_ADDR, &sso) == 0) &&
            ((sso & 0x01) != 0))
        {
            NFC_I2C_ADDRESS = NFC_BASE_ADDRESS;
            return true;
        }
    }

    NFC_I2C_ADDRESS = NFC_BASE_ADDRESS;
    return false;
}

/**
 * Get full Configuration
 */
uint8_t NFCGetData(uint8_t *url, uint8_t *pwr, uint8_t *adv, uint8_t *ep)
{

    uint8_t dummy[50] = {0};
    uint8_t index = 0;
    uint8_t url_len = 0;
    uint8_t ret = NFC_ERROR_READ;

    *pwr = 6;
    *adv = 10;
    *ep = 1;
    if (NfcTag_readBytes(0x00, dummy, sizeof(dummy)) != 0)
    {
        url[0] = 0;
        return NFC_ERROR_READ;
    }
    if ((dummy[0] == 0xE1) && (dummy[4] == 0x03))
    {

        if ((dummy[8] > 0) && (dummy[9] == 0x55))
        {
            url_len = dummy[8] - 1;
            if (url_len >= URL_BUFFER)
            {
                url_len = URL_BUFFER - 1;
            }
            if ((uint16_t)11 + url_len > sizeof(dummy))
            {
                url[0] = 0;
                return NFC_ERROR_READ;
            }
            for (index = 0; index < url_len; index++)
            {

                url[index] = dummy[11 + index];
            }
            url[url_len] = 0;

            index = dummy[8] + 13;
            if (index >= sizeof(dummy))
            {
                return ret;
            }
            ret = NFC_ONLY_URL;
        }
        if (dummy[index] == 0x54)
        {
            index = index + 4;
            if (dummy[index] == 0x2B)
            {
                index += 1;
                *pwr = (dummy[index] - '0');
                index += 1;
                if (dummy[index] != 0x2B)
                {
                    *pwr = ((*pwr) * 10) + (dummy[index] - '0');
                    index += 1;
                }
                ret = NFC_COMPLETE;
            }
            if (dummy[index] == 0x2B)
            {
                index += 1;
                *adv = (dummy[index] - '0');
                index += 1;
                if (dummy[index] != 0x2B)
                {
                    *adv = ((*adv) * 10) + (dummy[index] - '0');
                    index += 1;
                }
                ret = NFC_COMPLETE;
            }

            if (dummy[index] == 0x2B)
            {
                index += 1;
                *ep = (dummy[index] - '0');
                ret = NFC_COMPLETE;
            }
        }
    }
    return ret;
}

void NfcTag_HideConfig(uint8_t lengh)
{
    (void)st25dv_write_eeprom_byte_checked(NFC_BASE_ADDRESS, 0x05, lengh + 5);
    (void)st25dv_write_eeprom_byte_checked(NFC_BASE_ADDRESS, 0x06, 0xD1);
}

void NfcTag_submitPassWd(uint8_t *passWd)
{
    uint8_t data[17];
    uint8_t ret;

    memcpy(&data[0], passWd, PASSWORD_LENGTH);
    data[8] = ST25DV_I2C_PRESENT_PASSWORD;
    memcpy(&data[9], passWd, PASSWORD_LENGTH);

    NFC_I2C_ADDRESS = NFC_SYSTEM_ADDRESS;
    for (int attempt = 0; attempt < ST25DV_I2C_RETRY_COUNT; attempt++)
    {
        ret = NfcTag_writeBytes(ST25DV_I2C_PWD_ADDR, data, sizeof(data));
        if (ret == 0)
        {
            break;
        }
        k_msleep(ST25DV_EEPROM_WRITE_MS);
    }
    NFC_I2C_ADDRESS = NFC_BASE_ADDRESS;
}

void NfcTag_writePassWd(uint8_t *passWd)
{
    ARG_UNUSED(passWd);
}
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

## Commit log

2026-06-24 folder reorganization
    [Bill of Materials-G4y_SuperCap(Production_PG_Enable).xlsx, Bill of Materials-G4y_SuperCap(Production_PG_Enable_noDisplay).xlsx, CalcoloResistenze.xlsx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]
2026-06-26 Fixed wrong behaviour in low power mode, wrong pin reconfiguration
2026-06-26 Fix wrong DTS configuration, relevant for low power modes
2026-06-26 Fixing wrong low power mode handling
    [GDEW0154M10.c, NfcTag.c, main.c]
